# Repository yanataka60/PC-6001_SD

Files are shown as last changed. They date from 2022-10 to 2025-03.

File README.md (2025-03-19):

# PC-6001にSD-CARDからロード、セーブ機能

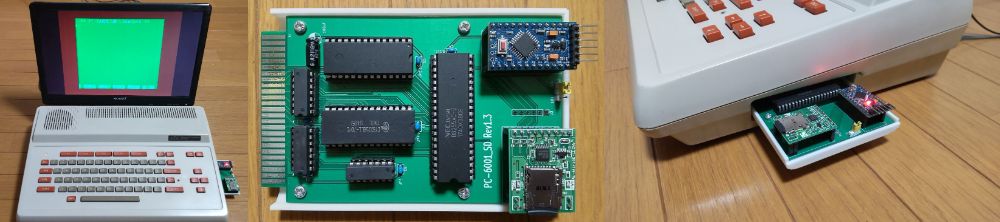
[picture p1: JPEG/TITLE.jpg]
TITLE


　PC-6001でSD-CARDからロード、セーブ機能を実現するものです。

　対応機種は初代PC-6001です。

　PC-6001mk2以降の機種でも動作しますが、MODE1、MODE2のみの動作となります。また、PC-6601、PC-6601SRはドライブ数切替スイッチは0として使ってください。なお、PC-6001mk2以降の機種では裏RAMにBASIC-ROMをコピーしてパッチを当てますのでBASIC-ROMを差し替える必要はありません。

　対応しているCMT形式は、P6形式(拡張子はP6、CASのどちらでも大丈夫)とP6T形式です。

　CMTからの読み込み実行に数分掛かっていたゲームも数十秒で実行できます。

　なお、Arduino、ROMへ書き込むための機器が別途必要となります。

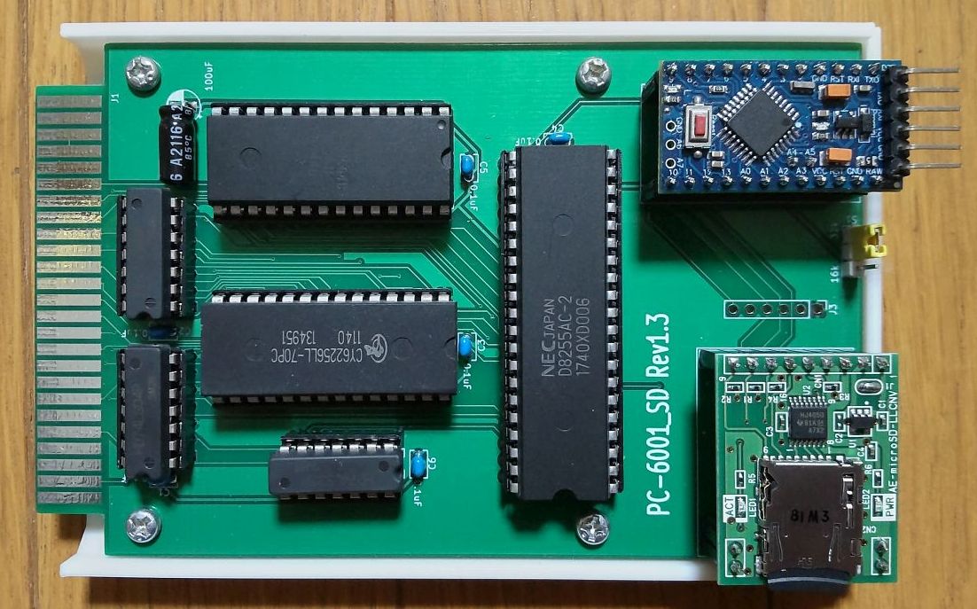
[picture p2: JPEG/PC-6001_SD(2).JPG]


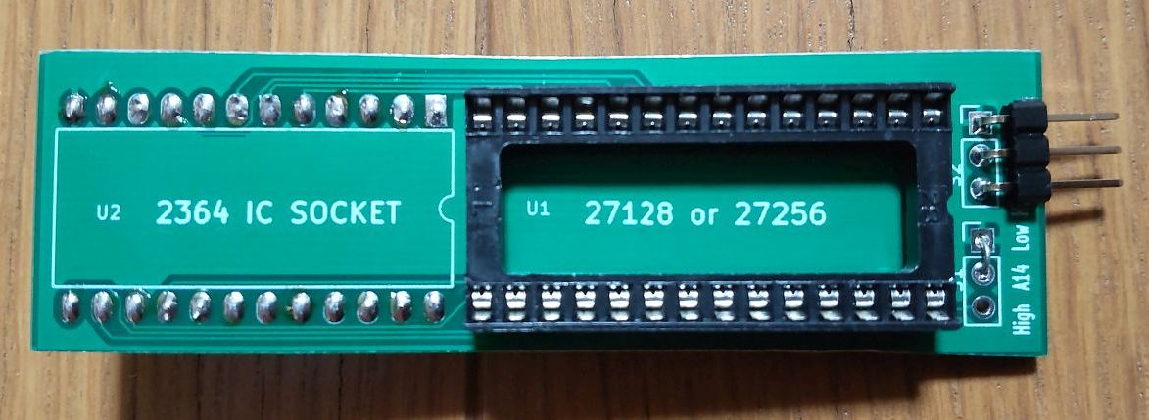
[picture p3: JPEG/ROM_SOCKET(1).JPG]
ROM_SOCKET


## 対応できないもの
　BASIC-ROMのCMT関連ルーチンにパッチを当てたROMに差し替えることでSD-CARDへのアクセスを実現していますのでBASIC-ROMのCMT関連ルーチンをコールせず独自にCMTからLOADするソフト（ロードランナー等）は対応できないので途中で止まります。

## 回路図
### PC-6001_SD基板
　KiCadフォルダ/PC-6001_SD内のPC-6001_SD.pdfを参照してください。

[回路図](https://github.com/yanataka60/PC-6001_SD/blob/main/Kicad/PC-6001_SD/PC-6001_SD.pdf)

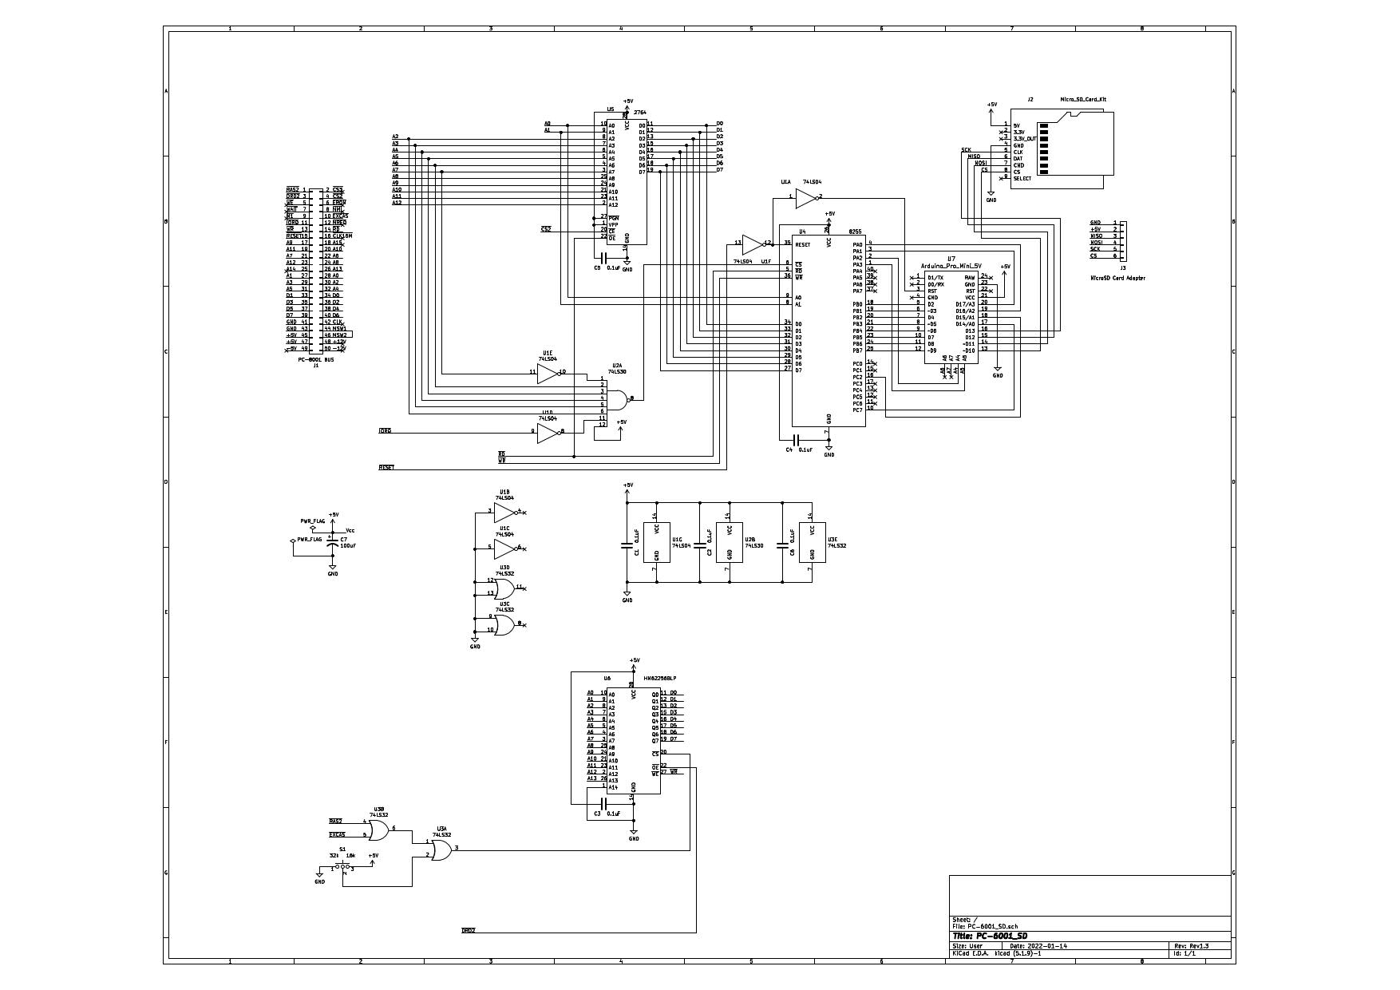
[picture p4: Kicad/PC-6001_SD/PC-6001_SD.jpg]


### BASIC-ROM挿し替え用基板
　KiCadフォルダ/ROM_SOCKET内のROM_SOCKET.pdfを参照してください。

[回路図](https://github.com/yanataka60/PC-6001_SD/blob/main/Kicad/ROM_SOCKET/ROM_SOCKET.pdf)

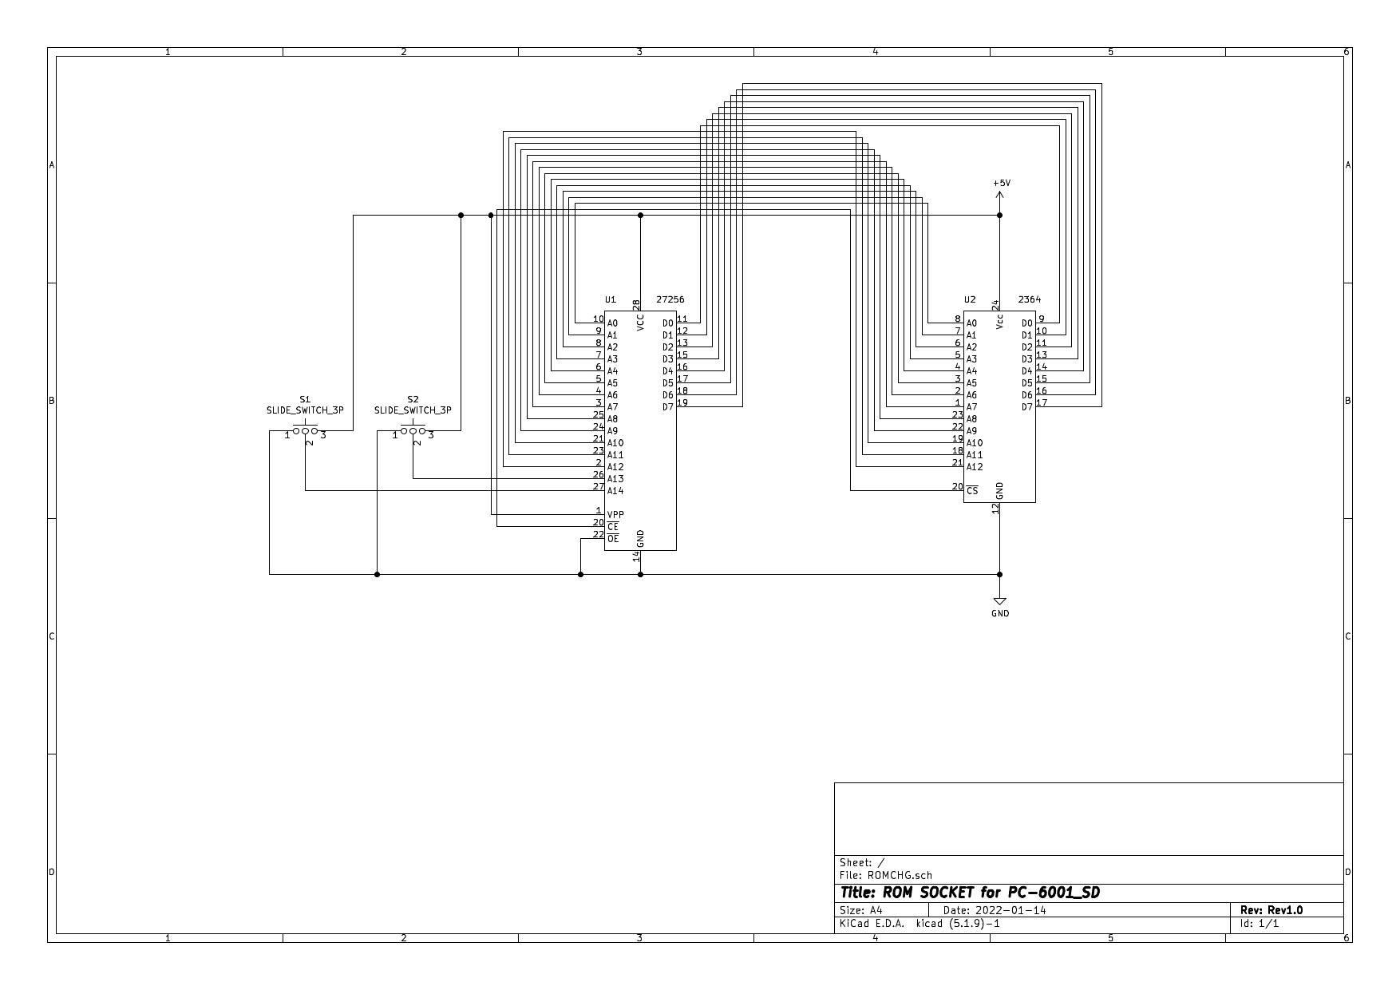
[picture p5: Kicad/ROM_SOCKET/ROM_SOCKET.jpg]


## 部品
### PC-6001_SD基板
|番号|品名|数量|備考|
| --- | --- | --- | --- |
||J2、J3のいずれか(注1)|||
|J2|Micro_SD_Card_Kit|1|秋月電子通商 AE-microSD-LLCNV (注2)|
|J3|MicroSD Card Adapter|1|Arduino等に使われる5V電源に対応したもの (注4)|
|U1|74LS04|1||
|U2|74LS30|1||
|U3|74LS32|1||
|U4|8255|1||
|U5|2764/28C64相当品|1||
|U6|SRAM 62256相当品|1||
|U7|Arduino_Pro_Mini_5V|1|Atmega328版を使用 168版は不可。(注3)|
|C1 C2 C3 C4 C5 C6|積層セラミックコンデンサ 0.1uF|6||
|C7|電解コンデンサ 16v100uF|1||
||ピンヘッダ|2Pin分|Arduino_Pro_MiniにはA4、A5用のピンヘッダが付いていないため別途調達が必要です 秋月電子通商 PH-1x40SGなど|
||ピンソケット(任意)|26Pin分|Arduino_Pro_Miniを取り外し可能としたい場合に調達します 秋月電子通商 FHU-1x42SGなど|

　　　注1)J2又はJ3のどちらかを選択して取り付けてください。

　　　注2)秋月電子通商　AE-microSD-LLCNVのJ1ジャンパはショートしてください。

　　　注3)Arduino Pro MiniはA4、A5ピンも使っています。

　　　注4)MicroSD Card Adapterを使う場合

　　　　　J3に取り付けます。

　　　　　MicroSD Card Adapterについているピンヘッダを除去してハンダ付けするのが一番確実ですが、J3の穴にMicroSD Card Adapterをぴったりと押しつけ、裏から多めにハンダを流し込むことでハンダ付けをする方法もあります。なお、この方法の時にはしっかりハンダ付けが出来たかテスターで導通を確認しておいた方が安心です。

ハンダ付けに自信のない方はJ2の秋月電子通商　AE-microSD-LLCNVをお使いください。AE-microSD-LLCNVならパワーLED、アクセスLEDが付いています。

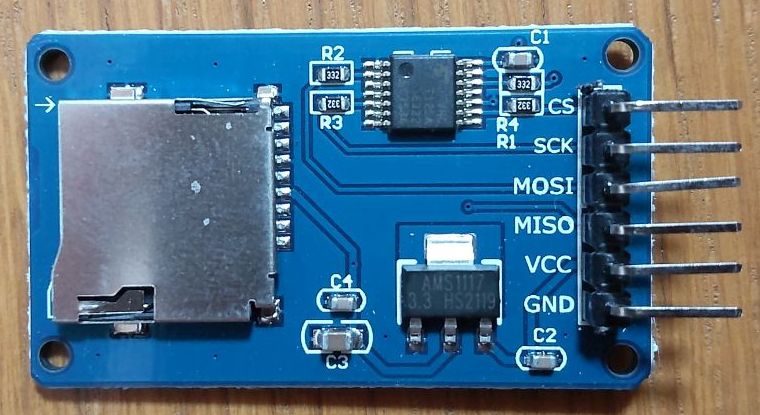
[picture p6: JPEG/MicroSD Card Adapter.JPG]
MicroSD Card Adapter1


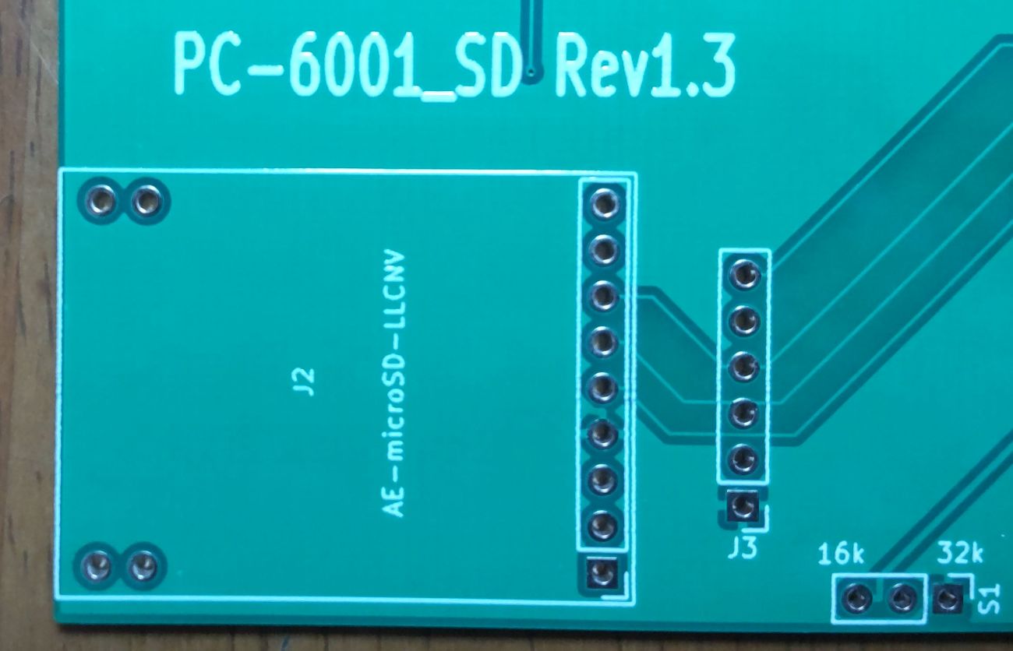
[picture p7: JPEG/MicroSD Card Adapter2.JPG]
MicroSD Card Adapter2


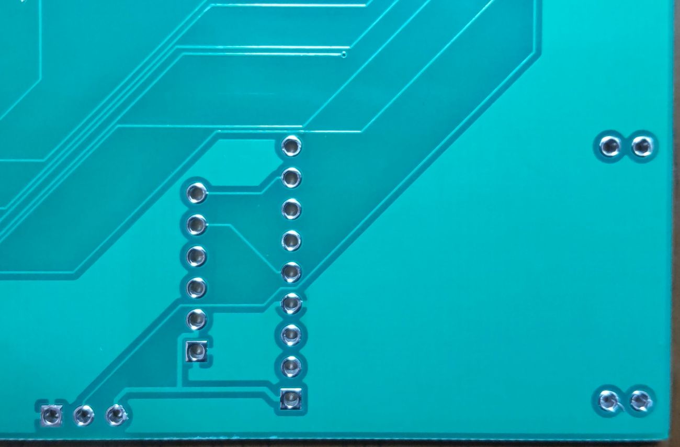
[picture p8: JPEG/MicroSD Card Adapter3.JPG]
MicroSD Card Adapter3


### BASIC-ROM挿し替え用基板
|番号|品名|数量|備考|
| --- | --- | --- | --- |
|S1|ジャンパー||27128はHigh(5V)、27256はLow(GND)に固定|
|S2|ピンヘッダＬ型 1x3(3P)|1|秋月電子通商 PH-1X3RG(2)など|
||ピンソケット(メス) 1x3(3P)又はコネクタ用ハウジング 3P + ケーブル用コネクタ|1|秋月電子通商 FH-1x3SG/RH 2226A-03 2226TGなど|
||3Pトグルスイッチ 1回路2接点 パネル取付用|1|秋月電子通商 1MS1-T1-B1-M1-Q-Nなど|
||配線材|約30cmx3||
|U1|27128又は27256相当品|1|28C256は不可、29C256は可|
|U2|基板用リードフレーム又は細ピンヘッダ|12Pinx2|秋月電子通商 SS2.54-6SN、PHA-1x40SGなど|

## ROMへの書込み
　Z80フォルダ内のEXT_ROM.binをROMライター(TL866II Plus等)を使って2764又は28C64に書き込みます。

## Arduinoプログラム
　PC-6001mk2_SDと全く同じものを使用しています。

　Arduino IDEを使ってPC-6001mk2_SDプロジェクトArduinoフォルダのPC-6001mk2_SDフォルダ内PC-6001mk2_SD.inoを書き込みます。

　SdFatライブラリを使用しているのでArduino IDEメニューのライブラリの管理からライブラリマネージャを立ち上げて「SdFat」をインストールしてください。

　「SdFat」で検索すれば見つかります。「SdFat」と「SdFat - Adafruit Fork」が見つかりますが「SdFat」のほうを使っています。

注)Arduinoを基板に直付けしている場合、Arduinoプログラムを書き込むときは、カートリッジスロットから抜き、74LS04を外したうえで書き込んでください。

## BASIC-ROMの挿し替え
### BASIC-ROMの抽出
　まず、PC-6001_SD基板を完成させ、拡張スロットに挿入して電源を入れます。

　画面に「PC-6001_SD Launcher」と表示されるので、STOPキー又は「1」コマンド、「B」コマンドでBASICを起動します。

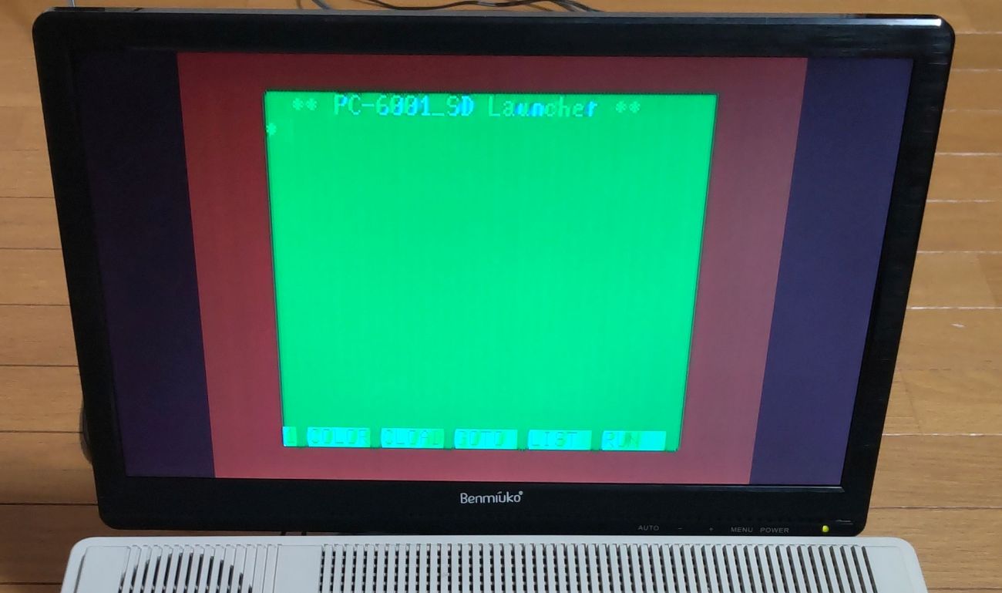
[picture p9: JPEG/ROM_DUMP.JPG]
ROM_DUMP


　入力待ちになったら「EXEC &H4013[CR]」と入力するとBASIC-ROMの内容をSD-CARDに保存するプログラムが実行されます。

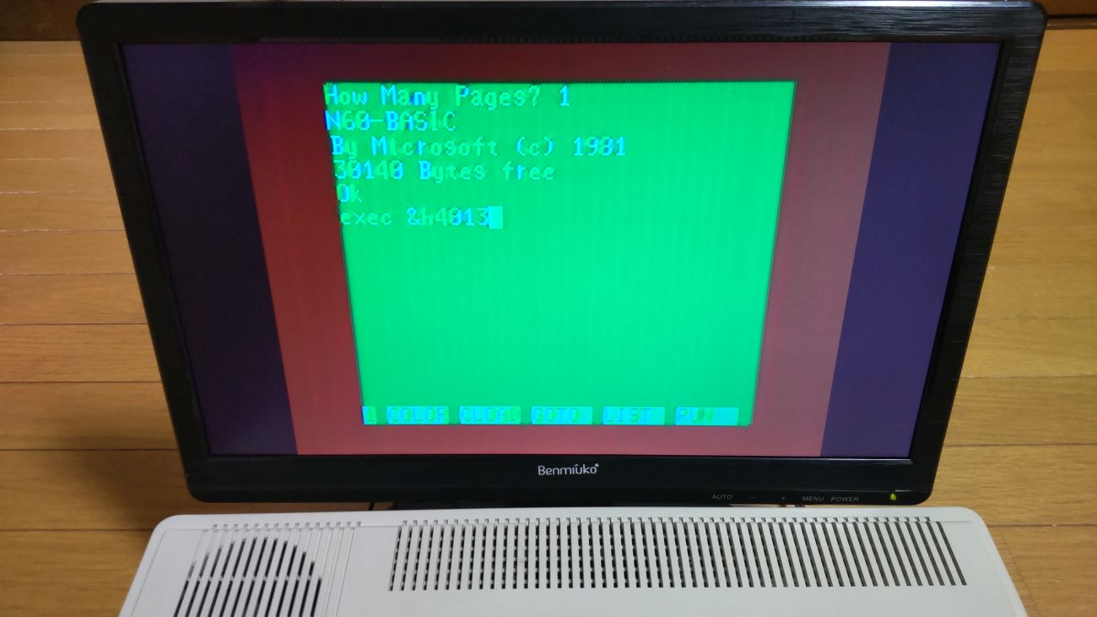
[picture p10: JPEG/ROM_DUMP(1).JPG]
ROM_DUMP1


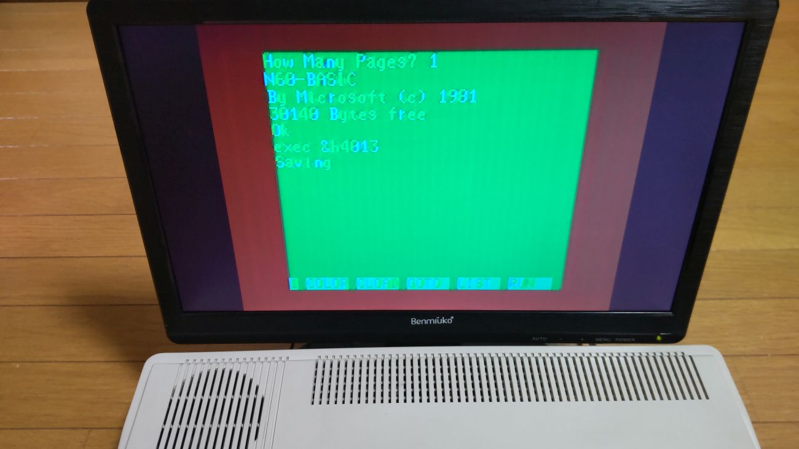
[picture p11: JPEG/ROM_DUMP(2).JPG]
ROM_DUMP2


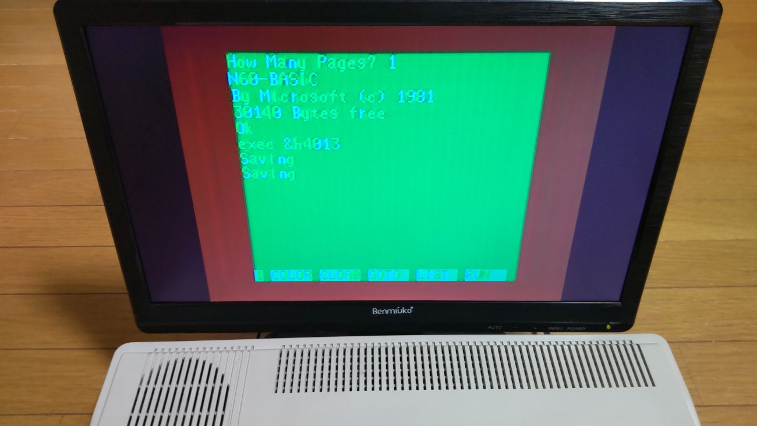
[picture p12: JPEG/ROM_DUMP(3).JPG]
ROM_DUMP3


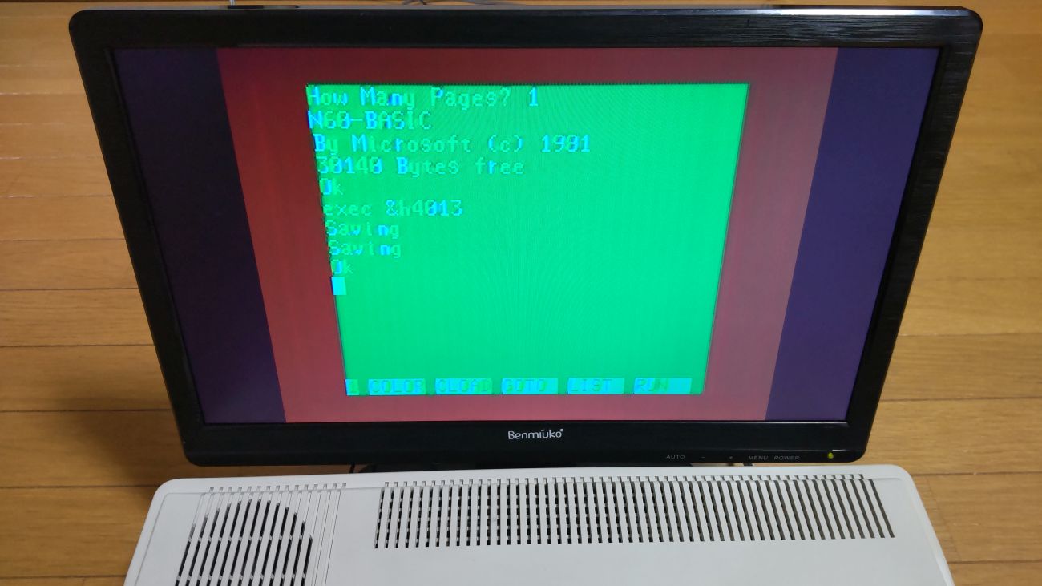
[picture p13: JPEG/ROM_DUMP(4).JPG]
ROM_DUMP4


　終わったらSD-CARDを抜き、Windowsパソコン等で内容を確認すると「ROM60A.CAS」と「ROM60B.CAS」という二つのファイルが作成されているはずです。

　「ROM60A.CAS」「ROM60B.CAS」とも拡張子を「.bin」に変更します。

　「ROM60A.bin」はBASIC-ROM全体(0000h～3FFFh)のダンプファイルです。Emulator等に使ってください。

　「ROM60B.bin」はBASIC-ROM前半(0000h～1FFFh)のダンプファイルでこちらにパッチを当て挿し替えることになります。

### BASIC-ROMへのパッチあて
　まず、「ROM60B.bin」をコピーし「ROM60C.bin」を作ります。

　「ROM60C.bin」の以下のアドレスを修正します。

|ADDRESS|修正前|修正後|
| --- | --- | --- |
|1A61|C5 D5 E5|C3 04 40|
|1A70|C5 D5 E5|C3 07 40|
|1AB8|C5 D5 E5|C3 0A 40|
|1ACC|C5 D5 E5|C3 0D 40|
|1B06|C5 D5 E5|C3 10 40|

　「ROM60B.bin」と「ROM60C.bin」をマージし、「ROM60.bin」として保存します。ROM60B.binが0000h～1FFFh、ROM60C.binが2000h～3FFFhとなります。

　出来上がった「ROM60.bin」を27128又は27256等に焼きます。

### BASIC-ROM挿し替え用基板の装着

　BASIC-ROM挿し替え用基板に27128を使うときはA14(S1)はHigh(5V)に固定します。

　27256を使うときは、A14(S1)はLow(GND)にします。が、A14もA13と同様に3Pスイッチで切り替えられるようにすれば4000h～7FFFhまでを使って4つまでBASIC-ROMを切り替えられるようにも出来ます。

ROM_SOCKET1

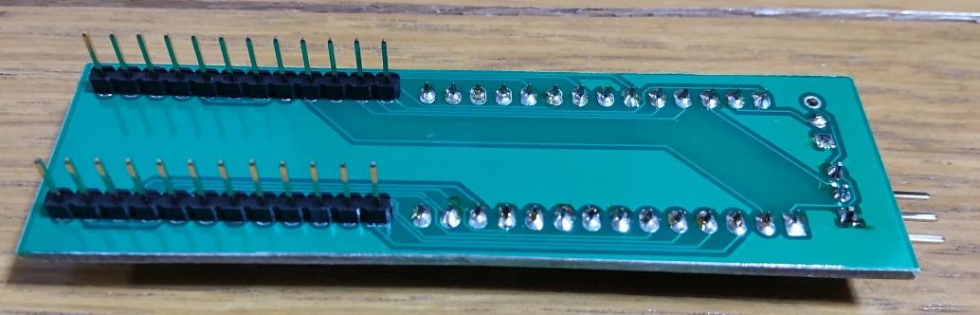
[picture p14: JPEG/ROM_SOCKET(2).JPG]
ROM_SOCKET2


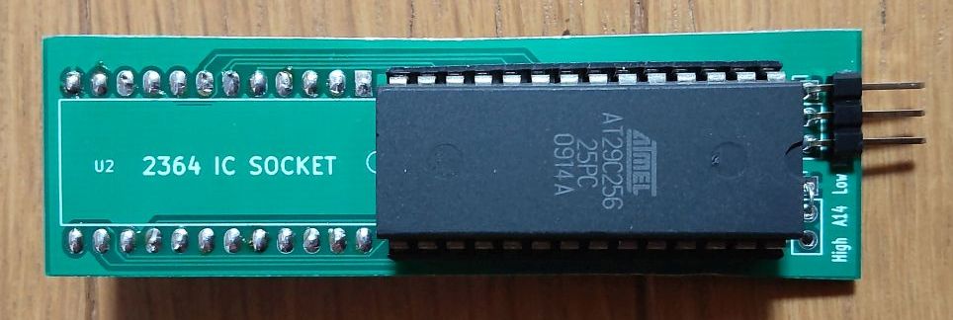
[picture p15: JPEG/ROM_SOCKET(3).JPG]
ROM_SOCKET3


　3PトグルスイッチによりCMTとSDを切り替えられるようにします。

　3PトグルスイッチはRS-232C用のパネルに穴を開けて取り付けるのがいいと思います。

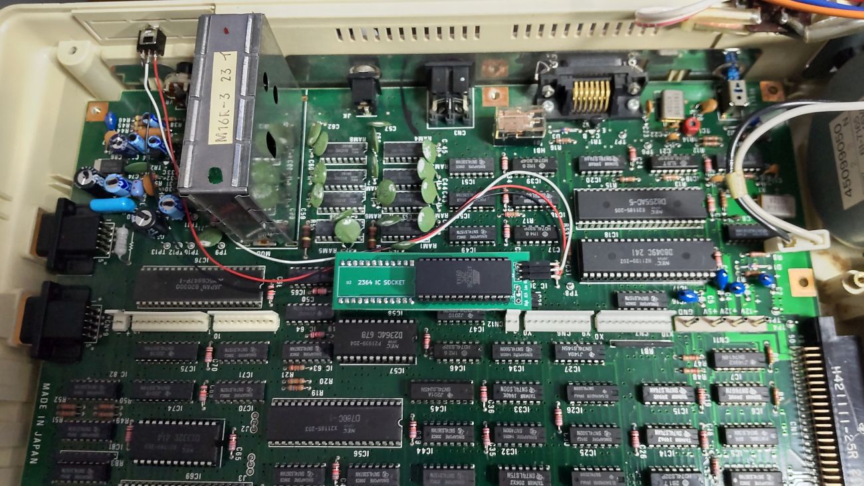
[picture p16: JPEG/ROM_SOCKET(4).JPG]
ROM_SOCKET4


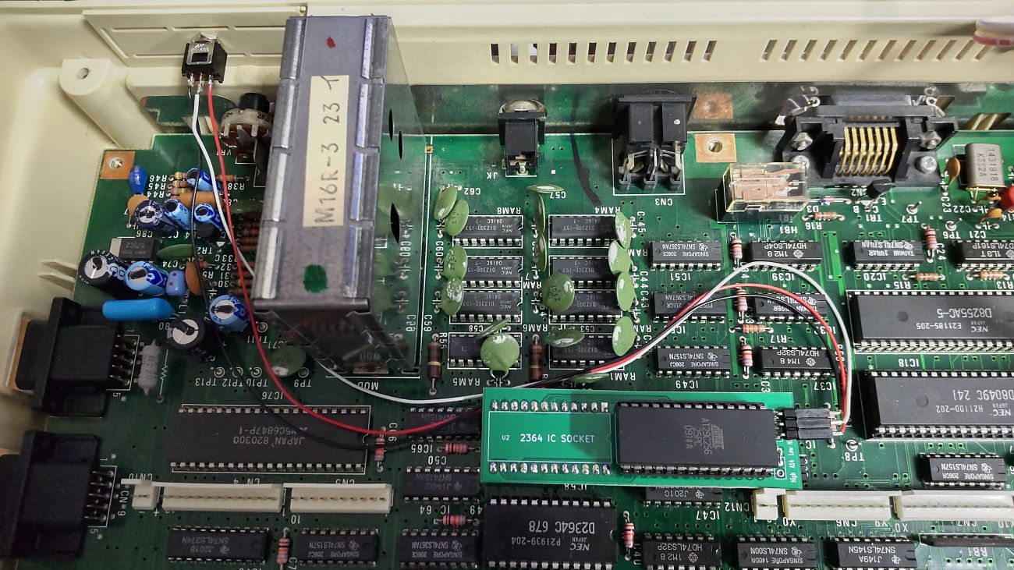
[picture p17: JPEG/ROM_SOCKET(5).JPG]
ROM_SOCKET5


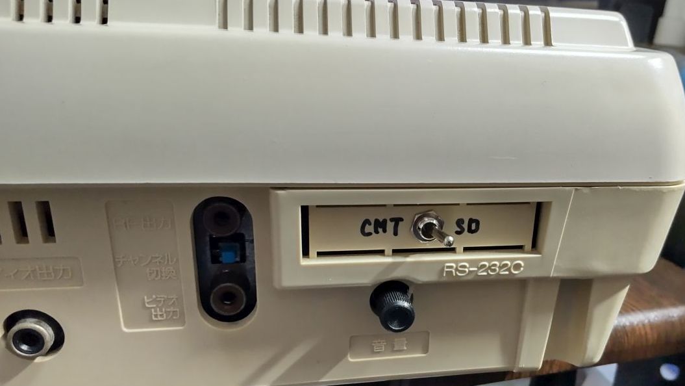
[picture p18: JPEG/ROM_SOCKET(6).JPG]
ROM_SOCKET6


## 接続
　カートリッジスロットに挿入します。

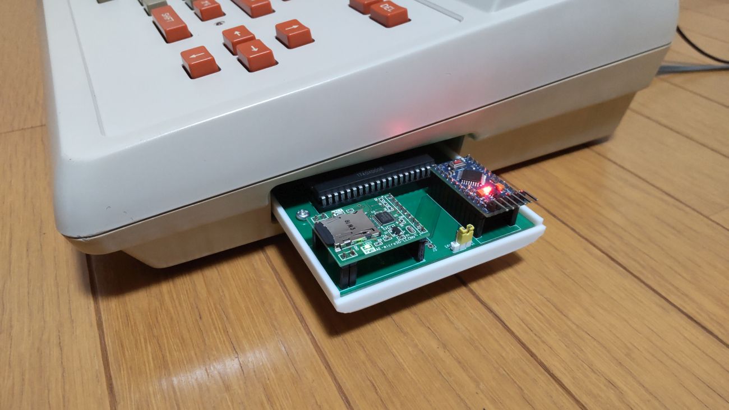
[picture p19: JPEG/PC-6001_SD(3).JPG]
cartridge


　カートリッジスロットへの抜き差しに基板のみでは不便です。

　STLフォルダに基板を載せられるトレイの3Dデータを置いたので出力して使うと便利です。

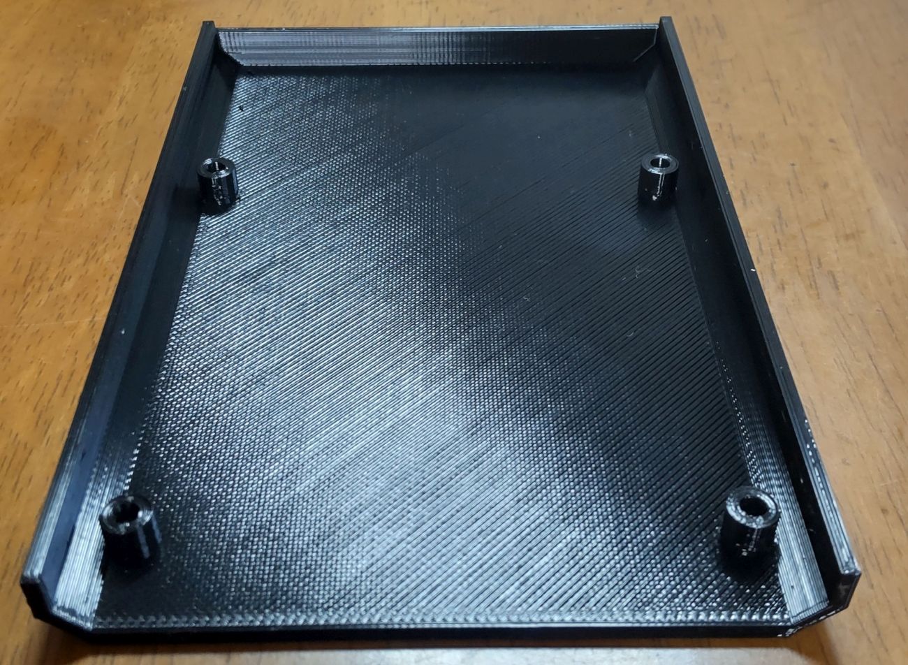
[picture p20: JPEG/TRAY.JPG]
Tray


　PC-6601、PC-6601SRはドライブ数切替スイッチは0として使ってください。

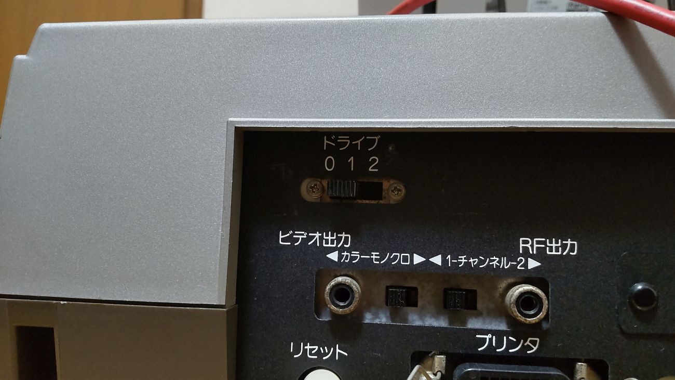
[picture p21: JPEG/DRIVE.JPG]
Drive


## SD-CARD
　出来れば8GB以下のSDカードを用意してください。

　ArduinoのSdFatライブラリは、SD規格(最大2GB)、SDHC規格(2GB～32GB)に対応していますが、SDXC規格(32GB～2TB)には対応していません。

　また、SDHC規格のSDカードであっても32GB、16GBは相性により動作しないものがあるようです。

　FAT16又はFAT32が認識できます。NTFSは認識できません。

　ルートに置かれた拡張子が「.P6T」又は「.CAS」の形式ファイルのみ認識できます。(以外のファイル、フォルダも表示されますがLOAD実行の対象になりません)

　ファイル名は拡張子を除いて32文字まで、ただし半角カタカナ、及び一部の記号はArduinoが認識しないので使えません。パソコンでファイル名を付けるときはアルファベット、数字および空白でファイル名をつけてください。

　起動直後の画面は横32文字表示です。拡張子を含めて27文字以下にしたほうが画面が乱れません。

## MODE選択
### 初代PC-6001
　MODE1、MODE2の切り替えは、PC-6001_SD基板上のRAM切替スイッチにより選択します。16K側でMODE1、32K側でMODE2です。

### PC-6001mk2以降
　PC-6001_SD基板上のRAM切替スイッチは16K側にしてください。

　通常に電源ON、またはRESETしたときにはMODE1となります。

　MODE2にしたい時は、数字の2キーを押したまま、電源ON、またはRESETしてください。

## 使い方
起動直後は拡張ROMのプログラムが走り、以下のコマンドが使えます。

### Launcherコマンド
#### 1[CR]
次に「How Many Pages?(1-4)」と聞いてくるので画面数を入力すると入力された数字の画面数でSD対応にして起動します。

#### B[CR]
SD対応せずにBASICを起動します。

[STOP]キーと動作は同じです。

#### [STOP]キー
SD対応せずにBASICを起動します。

B[CR]と動作は同じです。

#### F[CR]又はF 文字列[CR]
文字列を入力せずにF[CR]のみ入力するとSD-CARDルートディレクトリにあるファイルの一覧を表示します。

文字列を付けて入力すればSD-CARDルートディレクトリにあるその文字列から始まるファイルの一覧を表示します。

10件表示したところで指示待ちになるので打ち切るならESC又は↑を入力すると打ち切られ、Bキーで前の10件に戻ります。それ以外のキーで次の10件を表示します。

　行頭に「*L 」を付加して表示してあるので実行したいファイルにカーソルキーを合わせて[CR]キーを押すだけでLOAD可能です。

　LOADの挙動については次のLコマンドの記述を参照してください。

　表示される順番は、登録順となりファイル名アルファベッド順などのソートした順で表示することはできません。

##### 例)
　　F[CR]

　　F S[CR]

　　F SP[CR]

#### L DOSファイル名[CR]
指定したDOSフィル名のファイルをSD-CARDからLOADします。

ファイル名の最後の「.P6T」「.CAS」は有っても無くても構いませんが、無い場合は「.P6T」が指定されたものとみなします。

　例)

　　L TEST.P6T -> DOSファイル名「TEST.P6T」を読み込みます。

　　L TEST.CAS -> DOSファイル名「TEST.CAS」を読み込みます。

　　L TEST -> DOSファイル名「TEST.P6T」を読み込みます。

　選択したファイルが「P6T」形式の場合、設定されたPagesで起動したうえで自動実行文字列を実行します。

　選択したファイルが「CAS」形式の場合、「How Many Pages?(1-4)」と聞いてくるので画面数を入力、次に「Auto Run?(y/c/n)」と聞いてくるので「y」とすれば最後に「Auto Run?(y/c/n)」と聞いてくるので「y」とすれば起動直後にCLOAD[CR]RUN[CR]が実行され、「c」とすればCLOAD[CR]だけが実行、「n」とすれば何も実行されません。

#### 操作上の注意
　~~「SD-CARD INITIALIZE ERROR」と表示されたときは、SD-CARDをいったん抜き再挿入したうえでArduinoをリセットしてください。~~

　~~SD-CARDにアクセスしていない時に電源が入ったままで SD-CARDを抜いた後、再挿入しSD-CARDにアクセスすると「SD-CARD INITIALIZE ERROR」となる場合があります。再挿入した場合にはSD-CARDにアクセスする前にArduinoを必ずリセットしてください。~~

　~~SD-CARDの抜き差しは電源を切った状態で行うほうがより確実です。~~

　(2024.3.12) SD-CARDにアクセスしていない時に電源が入ったままでSD-CARDを抜くと再度SD-CARDを挿入してもSD-CARDにアクセスできない問題を解消しました。(Arduinoを最新版に書き換えてください)

　再度SD-CARDを挿入した後、Fコマンド、Lコマンド、CLOAD、CSAVE等でSD-CARDに3回ほどアクセスすれば復旧します。

### BASICコマンド
#### CLOAD "DOSファイル名"[CR]
指定したDOSフィル名のBASICプログラムをSD-CARDからLOADします。

ファイル名は6文字以内で必須です。6文字以上入力された場合には7文字以降は無視されます。ファイル名を入力せずにCLOAD[CR]とすると暴走します。

ファイル名の前に"(ダブルコーテーション)は必須ですが、ファイル名の後ろに"(ダブルコーテーション)は有っても無くても構いません。

ファイル名の最後に「.CAS」は必要ありません。「.CAS」が指定されたものとみなします。

　例)

　　CLOAD "TEST" -> DOSファイル名「TEST.CAS」を読み込みます。

　　CLOAD "TESTTEST" -> DOSファイル名「TESTTE.CAS」を読み込みます。

　　CLOAD "TEST.BAS.CMT" -> DOSファイル名「TEST.BA.CMT」を読み込みます。

#### CSAVE "DOSファイル名"[CR]
BASICプログラムを指定したDOSフィル名でSD-CARDに上書きSAVEします。

ファイル名は6文字以内で必須です。6文字以上入力された場合には7文字以降は無視されます。

ファイル名の前に"(ダブルコーテーション)は必須ですが、ファイル名の後ろに"(ダブルコーテーション)は有っても無くても構いません。

ファイル名の最後の「.CAS」は必要ありません。「.CAS」が指定されたものとみなします。

　例)

　　CSAVE "TEST" -> 「TEST.CAS」で保存される。

　　CSAVE "TESTTEST" -> 「TESTTE.CAS」で保存される。

## 謝辞
　基板の作成に当たり以下のデータを使わせていただきました。ありがとうございました。

　Arduino Pro Mini

　　https://github.com/g200kg/kicad-lib-arduino

　AE-microSD-LLCNV

　　https://github.com/kuninet/PC-8001-SD-8kRAM

## 追記
　2023. 3. 4 AUTO STARTの選択肢をy/c/nとし、CLOADも実行しない選択を追加

　　　　　　CLOAD、CSAVEがLOAD、SAVEと誤表記されていたものを修正

　2024.1.15 SDカードは8GB以下が望ましいことを追記。

　2024.3.12 電源が入ったままでSD-CARDを抜くと再度SD-CARDを挿入してもSD-CARDにアクセスできない問題を解消した。

　2025.3.20 P6形式が使えることが伝わりにくい表記を修正した。

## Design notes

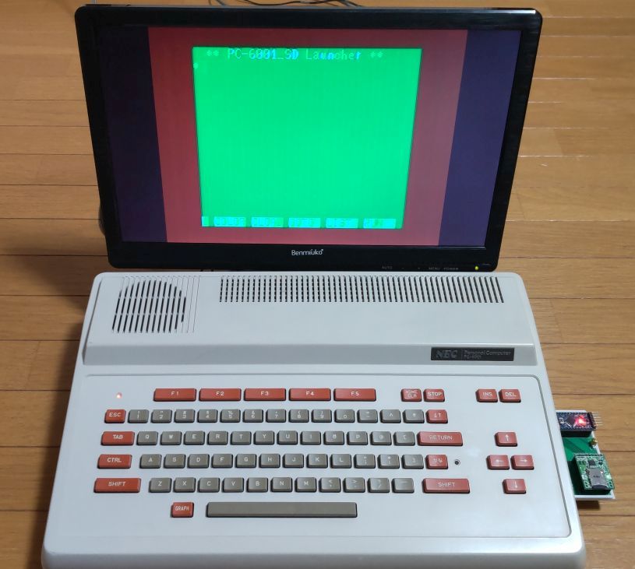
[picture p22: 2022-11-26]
JPEG/PC-6001_SD(1).JPG

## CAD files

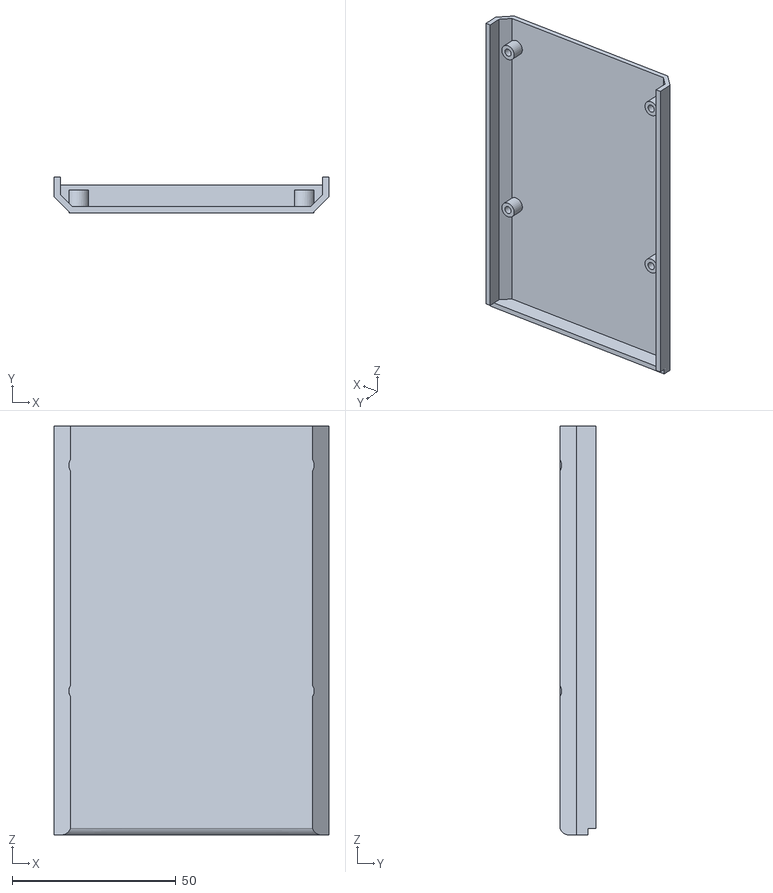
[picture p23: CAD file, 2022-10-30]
STL/PC-6001_SD_tray.stl
84.0 x 11.0 x 125.0

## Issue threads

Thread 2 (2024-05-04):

Arduino用ファイルがありません

ecmotto, 2024-05-04:
ArduinoフォルダのPC-6001mk2_SDフォルダ内PC-6001mk2_SD.inoファイルがないですよ。

yanataka60, 2024-05-04:
私の方では、PC-6001mk2_SD/Arduino/PC-6001mk2_SDフォルダ内にPC-6001mk2_SD.inoが見えますが、そちらでは見えないのでしょうか。
https://github.com/yanataka60/PC-6001mk2_SD/blob/main/Arduino/PC-6001mk2_SD/PC-6001mk2_SD.ino

ecmotto, 2024-05-05:
PC-6001mk2_SDにはありますが、この初代PC-6001用にはないですね。初代版でも、PC-6001mk2_SD内のPC-6001mk2_SD.inoが使用可能ということでしょうか？

yanataka60, 2024-05-05:
README.meに記載していたつもりですが、確かにPC-6001mk2_SDのArduinoフォルダを指しているとは不明確ですね。
「Arduino IDEを使ってArduinoフォルダのPC-6001mk2_SDフォルダ内PC-6001mk2_SD.inoを書き込みます。」を
「Arduino
IDEを使ってPC-6001mk2_SDプロジェクトArduinoフォルダのPC-6001mk2_SDフォルダ内PC-6001mk2_SD.inoを書き込みます。」に修正します。
------------------PC-6001_SDのREADME.me抜粋---------------------------------------------
Arduinoプログラム
Arduino IDEを使ってArduinoフォルダのPC-6001mk2_SDフォルダ内PC-6001mk2_SD.inoを書き込みます。
SdFatライブラリを使用しているのでArduino
IDEメニューのライブラリの管理からライブラリマネージャを立ち上げて「SdFat」をインストールしてください。
「SdFat」で検索すれば見つかります。「SdFat」と「SdFat - Adafruit
Fork」が見つかりますが「SdFat」のほうを使っています。
注)Arduinoを基板に直付けしている場合、Arduinoプログラムを書き込むときは、カートリッジスロットから抜き、74LS04を外したうえで書き込んでください。
------------------------------------------------------------------------------------------------------------

2024年5月5日(日) 14:04 ecmotto ***@***.***>:

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

yanataka60, 2024-05-05:
PC-8001mk2_SD、MZ-2000_SDのREADME.meには、「xxxx_SDと全く同じものを使用しています。」という記述をしていたのですが、PC-6001_SDのREADME.meには無いですね。
「PC-6001mk2_SDと全く同じものを使用しています。」という記述も追加します。
ご指摘ありがとうございました。

ecmotto, 2024-05-05:
対応いただきありがとうございました。今、ほとんどの部品をはんだ付けし終わったんですが、SRAMなど一部の部品の配達待ちです。動かすのが楽しみです！

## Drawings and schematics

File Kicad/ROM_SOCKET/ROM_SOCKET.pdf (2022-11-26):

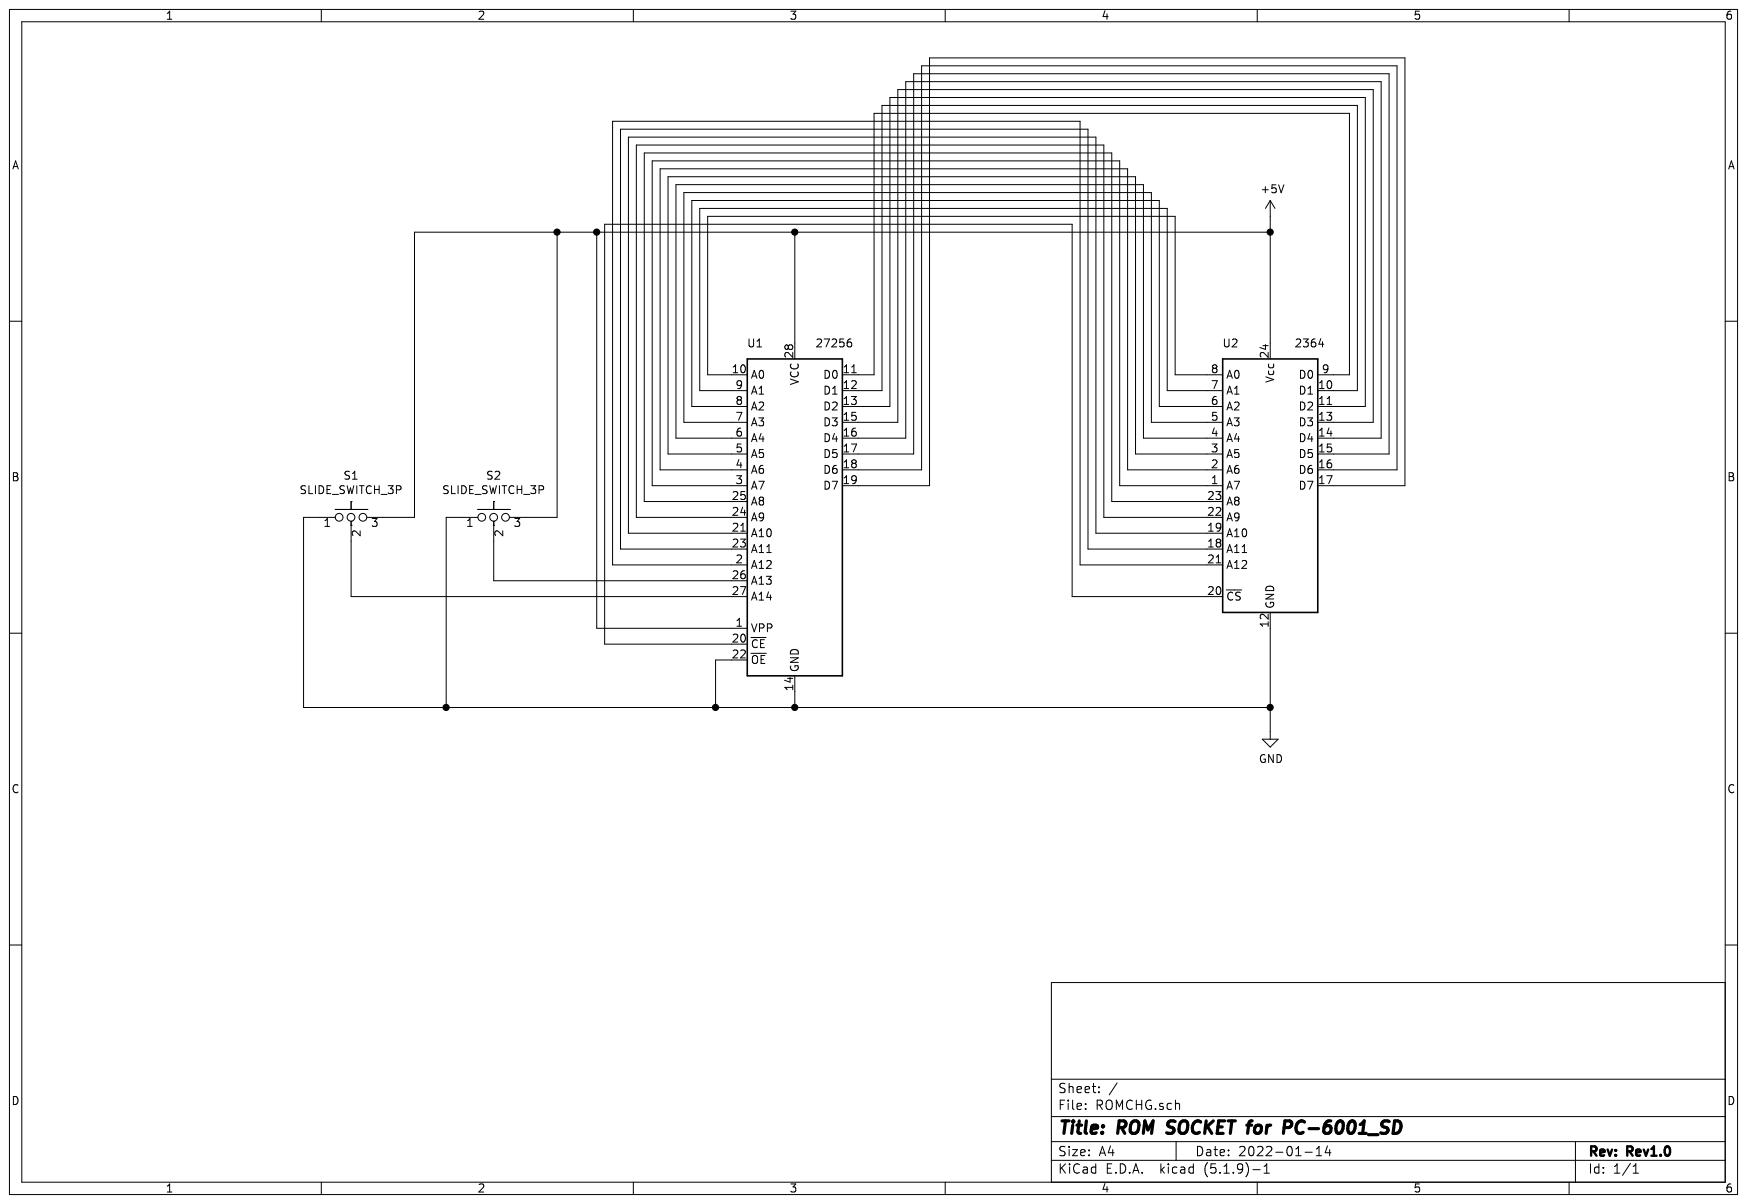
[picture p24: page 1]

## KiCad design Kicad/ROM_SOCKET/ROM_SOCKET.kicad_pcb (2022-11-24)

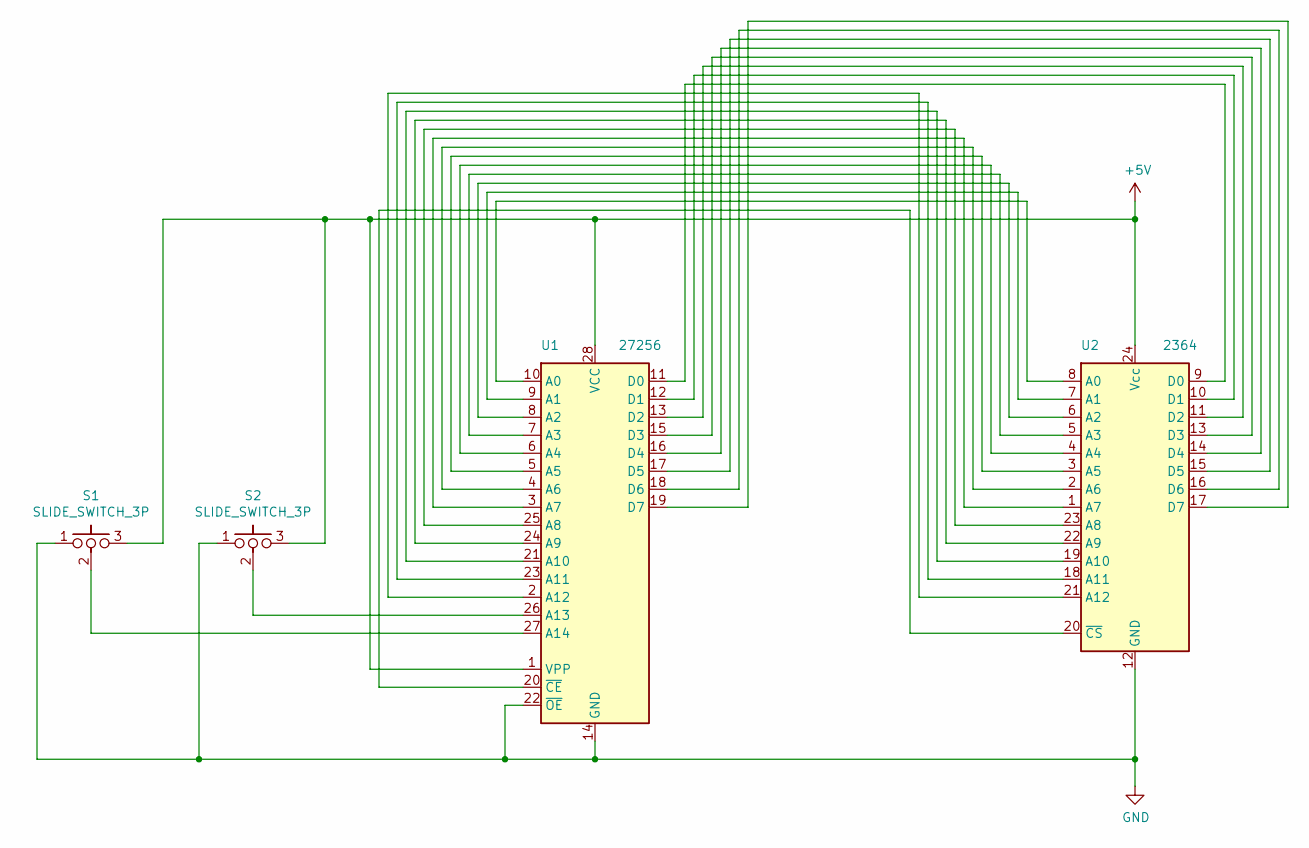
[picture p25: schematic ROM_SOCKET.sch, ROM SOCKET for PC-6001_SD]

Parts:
S1, S2: SLIDE_SWITCH_3P; PinHeader_1x03_P2.54mm_Vertical
U1: 27256; DIP-28_W15.24mm_LongPads
U2: 2364; DIP-24_W15.24mm_LongPads

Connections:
+5V: S1.3, S2.3, U1.1 (VPP), U1.28 (VCC), U2.24 (Vcc)
GND: S1.1, S2.1, U1.14 (GND), U1.22 (~OE), U2.12 (GND)
unnamed: S1.2, U1.27 (A14)
unnamed: S2.2, U1.26 (A13)
unnamed: U1.2 (A12), U2.21 (A12)
unnamed: U1.3 (A7), U2.1 (A7)
unnamed: U1.4 (A6), U2.2 (A6)
unnamed: U1.5 (A5), U2.3 (A5)
unnamed: U1.6 (A4), U2.4 (A4)
unnamed: U1.7 (A3), U2.5 (A3)
unnamed: U1.8 (A2), U2.6 (A2)
unnamed: U1.9 (A1), U2.7 (A1)
unnamed: U1.10 (A0), U2.8 (A0)
unnamed: U1.11 (D0), U2.9 (D0)
unnamed: U1.12 (D1), U2.10 (D1)
unnamed: U1.13 (D2), U2.11 (D2)
unnamed: U1.15 (D3), U2.13 (D3)
unnamed: U1.16 (D4), U2.14 (D4)
unnamed: U1.17 (D5), U2.15 (D5)
unnamed: U1.18 (D6), U2.16 (D6)
unnamed: U1.19 (D7), U2.17 (D7)
unnamed: U1.20 (~CE), U2.20 (~CS)
unnamed: U1.21 (A10), U2.19 (A10)
unnamed: U1.23 (A11), U2.18 (A11)
unnamed: U1.24 (A9), U2.22 (A9)
unnamed: U1.25 (A8), U2.23 (A8)

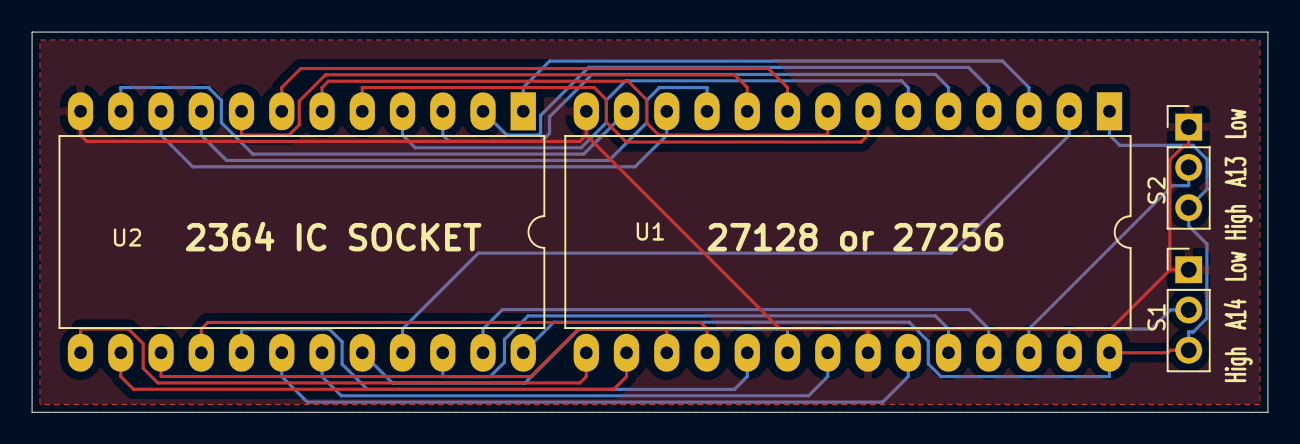
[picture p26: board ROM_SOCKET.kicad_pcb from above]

Board: 2 copper layers, 78.0 x 24.0 mm, 4 parts (0 on the bottom side), 26 nets.

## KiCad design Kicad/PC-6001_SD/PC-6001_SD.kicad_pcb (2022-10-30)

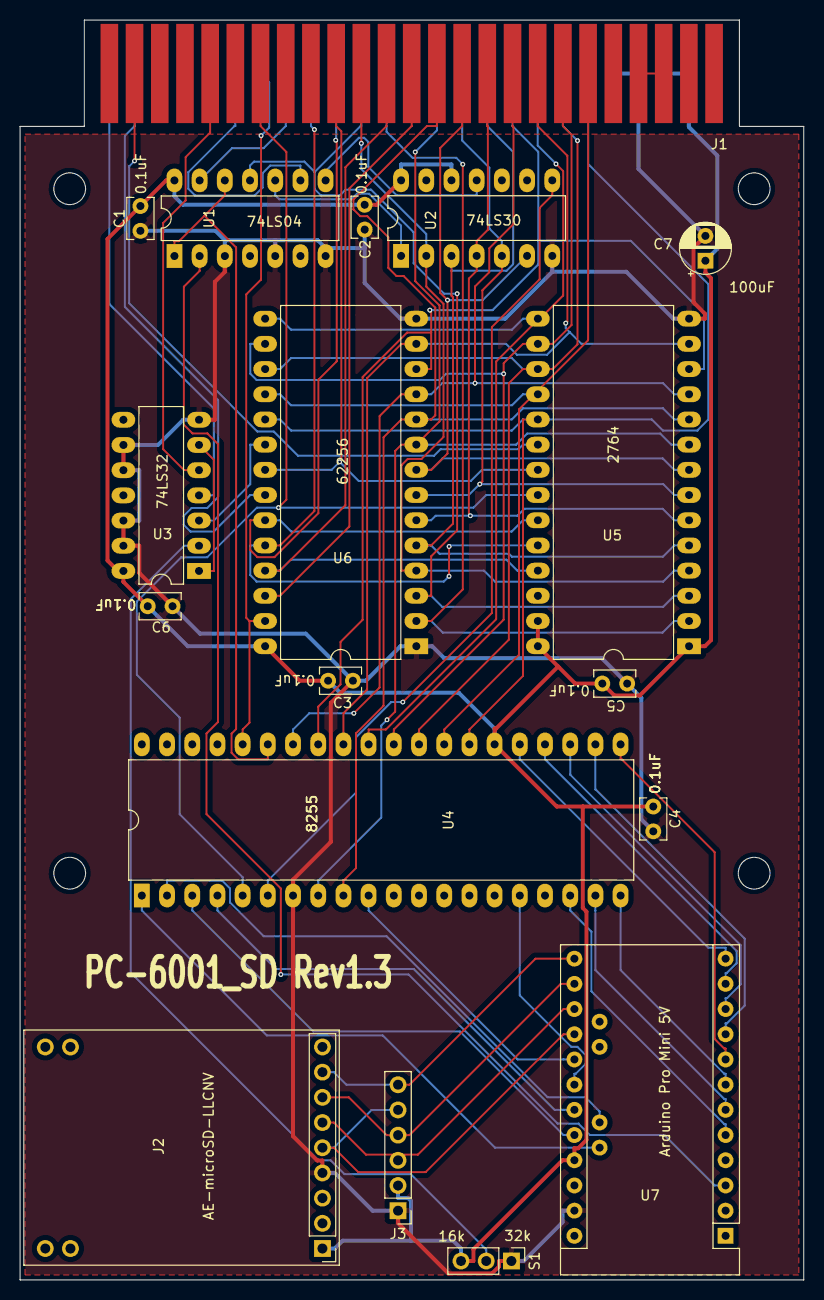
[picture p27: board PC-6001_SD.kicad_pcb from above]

Board: 2 copper layers, 79.0 x 127.0 mm, 22 parts (0 on the bottom side), 59 nets.

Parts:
C1, C2, C3, C4, C5, C6: 0.1uF; C_Rect_L4.0mm_W2.5mm_P2.50mm
C7: 100uF; CP_Radial_D5.0mm_P2.50mm
J1: PC-8001 BUS; BUS_50Pin
J2: Micro_SD_Card_Kit; AE-microSD-LLCNV
J3: MicroSD Card Adapter; PinHeader_1x06_P2.54mm_Vertical
MH1, MH2, MH3, MH4: MountingHole_3.2mm_M3
S1: 32k 16k; PinHeader_1x03_P2.54mm_Vertical
U1: 74LS04; DIP-14_W7.62mm_LongPads
U2: 74LS30; DIP-14_W7.62mm_LongPads
U3: 74LS32; DIP-14_W7.62mm_LongPads
U4: 8255; DIP-40_W15.24mm_LongPads
U5: 2764; DIP-28_W15.24mm_LongPads
U6: HM62256BLP; DIP-28_W15.24mm_LongPads
U7: Arduino_Pro_Mini_5V; Arduino_Pro_Mini

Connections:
+5V: C1.2, C2.2, C3.1, C4.1, C5.1, C6.2, C7.1, J1.45, J1.47, J2.1, J3.2, S1.3, U1.14, U2.12, U2.14, U3.14, U4.26, U5.1, U5.27, U5.28, U6.28, U7.21
/A0: J1.28, U4.9, U5.10, U6.10
/A1: J1.27, U4.8, U5.9, U6.9
/A2: J1.30, U2.6, U5.8, U6.8
/A3: J1.29, U2.5, U5.7, U6.7
/A4: J1.32, U2.4, U5.6, U6.6
/A5: J1.31, U2.3, U5.5, U6.5
/A6: J1.22, U2.2, U5.4, U6.4
/A7: J1.21, U1.11, U5.3, U6.3
/A8: J1.24, U5.25, U6.25
/A9: J1.17, U5.24, U6.24
/A10: J1.20, U5.21, U6.21
/A11: J1.19, U5.23, U6.23
/A12: J1.23, U5.2, U6.2
/A13: J1.26, U6.26
/CS: J2.8, J3.6, U7.13
/D0: J1.34, U4.34, U5.11, U6.11
/D1: J1.33, U4.33, U5.12, U6.12
/D2: J1.36, U4.32, U5.13, U6.13
/D3: J1.35, U4.31, U5.15, U6.15
/D4: J1.38, U4.30, U5.16, U6.16
/D5: J1.37, U4.29, U5.17, U6.17
/D6: J1.40, U4.28, U5.18, U6.18
/D7: J1.39, U4.27, U5.19, U6.19
/MISO: J2.6, J3.3, U7.15
/MOSI: J2.7, J3.4, U7.14
/MSW1: J1.44, J1.46
/SCK: J2.5, J3.5, U7.16
/~CS2: J1.4, U5.20
/~DRD2: J1.3, U6.22
/~EXCAS: J1.10, U3.5
/~IORQ: J1.11, U1.9
/~RAS2: J1.1, U3.4
/~RD: J1.14, U4.5, U5.22
/~RESET: J1.15, U1.13
/~WR: J1.13, U4.36, U6.27
GND: C1.1, C2.1, C3.2, C4.2, C5.2, C6.1, C7.2, J1.41, J1.43, J2.4, J3.1, S1.1, U1.3, U1.5, U1.7, U2.7, U3.7, U3.9, U3.10, U3.12, U3.13, U4.7, U5.14, U6.1, U6.14, U7.23
unnamed: S1.2, U3.2
unnamed: U1.1, U1.12, U4.35
unnamed: U1.2, U7.3
unnamed: U1.8, U2.11
unnamed: U1.10, U2.1
unnamed: U2.8, U4.6
unnamed: U3.1, U3.6
unnamed: U3.3, U6.20
unnamed: U4.1, U7.A5
unnamed: U4.2, U7.A4
unnamed: U4.3, U7.20
unnamed: U4.4, U7.19
unnamed: U4.10, U7.17
unnamed: U4.16, U7.18
unnamed: U4.18, U7.5
unnamed: U4.19, U7.6
unnamed: U4.20, U7.7
unnamed: U4.21, U7.8
unnamed: U4.22, U7.9
unnamed: U4.23, U7.10
unnamed: U4.24, U7.11
unnamed: U4.25, U7.12
